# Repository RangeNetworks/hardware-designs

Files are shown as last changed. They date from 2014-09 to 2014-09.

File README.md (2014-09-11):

Range Networks SDR1 Open Source Software-Defined Radio
======================================================

The Range Networks SDR1 consists of two individual PCBs that work in tandem, referred to as the SDR module and the RF module (or board). The SDR module provides signal processing and digital data transfer between the RF signals and the host. The RF module provides the wireless transmission of the data. The SDR and RF module boards are each on a 5.5" x 3.25" PCB outline. This is a stacked design with a single interface connector between them. The RF module uses the same PCB layout with different component stuffing options and is capable of supporting the following frequency bands: 850, 900, 1800, 1900 MHz. The SDR1 is based in large part on the USRP1 design.

The design resources provided are as follows:

- Software-defined radio (SDR) module
  - Schematics in pdf format
  - BOM in text format
  - Gerber files with assembly and fabrication drawings
  - NVM file for Silicon Labs Si5332C OTP eeprom
- RF module
  - Schematics in pdf format
  - BOM in text format: Low band and High band
  - Gerber files with assembly and fabrication drawings

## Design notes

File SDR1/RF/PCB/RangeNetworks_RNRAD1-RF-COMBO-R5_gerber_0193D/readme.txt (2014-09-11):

ALL OF THE RAD1 PCB DESIGN IS PROVIDED UNDER THE TERMS OF THIS CREATIVE COMMONS PUBLIC LICENSE ("CCPL" OR "LICENSE"). 
THE WORK IS PROTECTED BY COPYRIGHT AND/OR OTHER APPLICABLE LAW. ANY USE OF THE WORK OTHER THAN AS 
AUTHORIZED UNDER THIS LICENSE OR COPYRIGHT LAW IS PROHIBITED. 

See http://creativecommons.org/licenses/by-sa/3.0/legalcode

Board Name: RF-Combo 			Customer: Range Networks
Fab Part Number: RNRAD1-RF-COMBO-R5	Revision: 5

ARTWORK FILENAME CONTROL CHART:

GERBER FILENAME	   		PCB DESIGN LAYER

layer01.art		=    	top - component side
layer02.art		=	layer 02 - gnd plane
layer03.art		=	layer 03 - pwr plane
layer04.art		=	bottom - solder side

paste_top.art      	=	component side pastemask
paste_bot.art     	=	solder side pastemask
silk_top.art      	=	component side silkscreen
silk_bot.art     	=	solder side silkscreen
solder_top.art		=	component side soldermask
solder_bot.art		=	solder side soldermask

fab.art			=	fabrication drawing
assy.art		=	assembly drawing

Reference Drawings:

fab.PDF			=	fabrication drawing
assy.PDF		=	assembly drawing 

Additional Support Files:
	
RNRAD1-RF-COMBO-R5-1-4.drl	NC Drill information Layer 1 to 4
RNRAD1-RF-COMBO-R5.cad		FABmaster extract file
RNRAD1-RF-COMBO-R5.ipc		Export of IPC 356D netlist
RNRAD1-RF-COMBO-R5.rou		Route file
rnrad1-rf-combo-r5.tgz		Valor ODB++
art_param.txt			Gerber output setup information
ncdrill.log			NC Drill report
nc_param.txt			NC Parameter report
place_txt.txt			Export of assembly component placement
readme.txt	 		Gerber ZIP file content information

Special notes:

1. Two shorts in Valor - U3 and U6 pin 2 connects to their tabs (a mech pin).
2. There are two known dangling traces, leave them please.

=================================================
Rocket EMS, Inc
2380 Bering Drive
San Jose, Ca 95131

Design contact: Craig Schieferstein (408)955-0528 x1203 cell (408)888-7351
Email contact: cschieferstein@rocketems.com
Sales contact: Scott Schaetzle (408)315-5192

If there are any question regarding the data please call Craig Schieferstein.

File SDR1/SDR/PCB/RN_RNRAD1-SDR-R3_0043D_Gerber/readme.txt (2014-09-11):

ALL OF THE RAD1 PCB DESIGN IS PROVIDED UNDER THE TERMS OF THIS CREATIVE COMMONS PUBLIC LICENSE ("CCPL" OR "LICENSE"). 
THE WORK IS PROTECTED BY COPYRIGHT AND/OR OTHER APPLICABLE LAW. ANY USE OF THE WORK OTHER THAN AS 
AUTHORIZED UNDER THIS LICENSE OR COPYRIGHT LAW IS PROHIBITED. 

See http://creativecommons.org/licenses/by-sa/3.0/legalcode

Board Name: SDR 				Customer: Range Networks
Fab Part Number: RNRAD1-SDR-R3		Revision: 3

ARTWORK FILENAME CONTROL CHART:

GERBER FILENAME		PCB DESIGN LAYER

layer01.art		=    	top - component side
layer02.art		=	layer 02 – gnd plane
layer03.art		=	layer 03 – sig1 signal
layer04.art		=	layer 04 – sig2 signal
layer05.art		=	layer 05 – pwr plane
layer06.art		=	bottom - solder side

paste_top.art		=	component side pastemask
paste_bot.art		=	solder side pastemask
silk_top.art		=	component side silkscreen
silk_bot.art		=	solder side silkscreen
solder_top.art		=	component side soldermask
solder_bot.art		=	solder side soldermask
fab.art			=	fabrication drawing
assy.art			=	assembly drawing

Reference Drawings:

fab.PDF			=	fabrication drawing
assy.PDF		=	assembly drawing 

Additional Support Files:
	
RNRAD1-SDR-R3-1-6.drl		NC Drill information Layer 1 to 6
RNRAD1-SDR-R3.cad		FABmaster extract file
RNRAD1-SDR-R3.ipc		Export of IPC 356D netlist
RNRAD1-SDR-R3.rou		Route file
RNRAD1-SDR-R3.tgz		Valor ODB++
art_param.txt			Gerber output setup information
ncdrill.log				NC Drill report
nc_param.txt			NC Parameter report
place_txt.txt			Export of assembly component placement
readme.txt	 		Gerber ZIP file content information

==================================================================
If you would like to order PCBs directly you may contact the following

Rocket EMS, Inc
2380 Bering Drive
San Jose, Ca 95131

Sales contact: Scott Schaetzle (408)636-1616 cell (408)315-5192
Design contact: Donn Grigsby (408)636-1607 cell (510)590-3007
Email contact: dgrigsby@rocketems.com

If there are any question regarding the data please call Donn Grigsby.

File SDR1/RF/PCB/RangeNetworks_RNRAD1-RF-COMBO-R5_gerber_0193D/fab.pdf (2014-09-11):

0.062
10%
.5 oz

1.0 oz

1.0 oz

.5 oz

1.4

12.3
0.6

28.0
1.2

12.3
1.2

1.4
0.6

NESS

THICK

PLATING

PLATING

2X2113 1X2116

2X2113 1X2116
CORE

LAYER04 BOTTOM

LAYER03 PWR

LAYER02 GND

LAYER01 TOP

LAYER

23.0 mils

19.0 mils

23.0 mils

LINE WIDTH

50

50

50

IMPEDANCE

+/- 10%

+/- 10%

+/- 10%

# SEE NOTES

16. Add thieving to balance the copper distribution. The thieving consists of
15. Data Verification
14. Markings
13. Inspection
12. Impedance controlled construction and certification is required.
11. Bow and twist
10. Packaging
9. Cleanliness
8. Electrical test
7. Silkscreen
6. Finish
5. Remove all unused inner layers pads.
4. Drilling
3. Soldermask
2. Material
1. Specifications (unless otherwise specified):

15.0 Vendor will do a netlist to Gerber compare with the supplied

14.0 Fab will be permanently marked or etched with

Rocket EMS

13.0 Automatic optical inspection of all layers required.

(.007" per linear inch).

11.0 Maximum board warpage in any direction shall not exceed 0.7%

10.0 There shall be a max of 25 units per package, individually wrapped

9.1 Finished boards must conform to no more than 10 uG/in(squared) ionic

9.0 Boards shall be free of fiber glass dust or any other foreign material.

The test system shall provide a means of limiting the energy delivery to

Isolation Resistance: 10M Ohms, measured with a voltage of 200 Volts.

test not to exceed 10 Volts.

10 milliAmperes or less. Maximum open circuit voltage during continuity

8.2 Continuity: Test threshold not to exceed 10 Ohms, using a test current of

8.1 Apply test stamp in an area clear of silk and parts on solder side of PCB.

8.0 All boards must be 100% electrically tested for open and shorts at10 Volts.

7.4 Registration to be +/-.005 and must pass peel test.

7.3 Minimum clearance between silkscreen legend and vias, pads or holes,

7.2 Burn out silkscreen with soldermask.

7.1 No silkscreen allowed on exposed lands or in holes.

7.0 Silkscreen using | non-conductive epoxy or equivalent (both sides).

6.2 Finished boards shall not have nicks, scratches,

6.1 Plate holes thru with copper .0010 min to .002 max. thickness. Finished

6.0 Surface finish: Immersion gold, 2-5 micro-inches over 100

4.4 Minimum annular ring is 0.001". No breakout is permitted.

4.3 An N.C Drill file has been supplied-see drill table.

4.2 All hole diameters to be +/-.003 unless otherwise specified.

4.1 All holes to be +/-.003 from true position unless otherwise specified.

4.0 All hole diameters are finished sizes.

3.2 Via pads are encroached. Bottom side test pad vias are exposed.

3.1 Soldermask over -

3.0 Soldermask both sides with ( | color) liquid

2.3 Number of Layers:

2.2 Color to be opaque.

2.1 See stack up for copper weights

2.0 Natural Epoxy/Glass Laminate

1.3 Board must be compliant with UL 94V-0 .

1.2 Use | PCB artwork

1.1 Producibility study - it is the responsibility of the supplier

1.0 Unless otherwise defined on this drawing, fabricate board per

features will be maintained.

50 mil round pads on 100 mil centers. A 100 mil keepout of all etched

contamination.

to be .005

their e-mail address is located in the readme.txt.

An e-mail confirmation is required and should be sent to the designer found written permission must be obtained prior to proceeding.

IPC-356D file prior to releasing to manufacturing. If discrepancies are

Manufacturer's logo, date of Fab manufacture and UL 94V-0 rating.

and packaged so as to prevent damage during handling,shipping and storage.

voids, exposed copper, poor plating or mis-drilled holes.

hole size dimensions apply after plating.

micro-inches minimum of electroless nickel photo-imageable soldermask, .003 max. thickness.

measured over area free of soldermask.

w/Tg min of 170 degrees Celsius, thick +/-10 % standards, and of any specifications that cannot be met.

corrections made or recomendations to ensure conformance to

(in advance of manufacturing) of any changes, revisions, or

applicable specifications. | must be advised in writing

anufacturability in the supplier's process compliant to all

to conduct a thorough review of the artwork and media for

Current Revision of IPC-6012, Class 2 requirements.

Range Networks

03/22/12

white

bare copper.

4

Range Networks

green

FR-4.
.062

RNRAD1-RF-COMBO-R5

# RF-COMBO BOARD

# RANGE NETWORKS

# FAB DRAWING

Range Networks

5

# 1 RNRAD1-RF-COMBO-R5

FIGURE | SIZE | TOLERANCE | PLATED | QTY
| 0.010 | +.003/-.010 | PLATED | 330
| 0.012 | +.003/-.012 | PLATED | 633
| 0.018 | +/-.002 | PLATED | 46
| 0.040 | +/-.003 | PLATED | 7
| 0.060 | +/-.003 | PLATED | 10
| 0.070 | +/-.003 | PLATED | 21
| 0.125 | +/-.003 | PLATED | 4
| 0.040 | +/-.003 | NON-PLATED | 2

ALL UNITS ARE IN INCHES

HOLE CHART

| DRAWING REV 07
.005 1 .01 | | | RNRAD1-RF-COMBO-R5 | 5
SCALE: NONE | | SHEET 1OF 1

DESCRIPTION

.110

.789

2.211

3.000

3.110

0

.1100
.621

5.42

## REF

5.200

5.310

3.22

## REF

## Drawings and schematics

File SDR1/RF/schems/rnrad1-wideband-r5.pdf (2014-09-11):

## DGND ON DYN?

### IOB_P

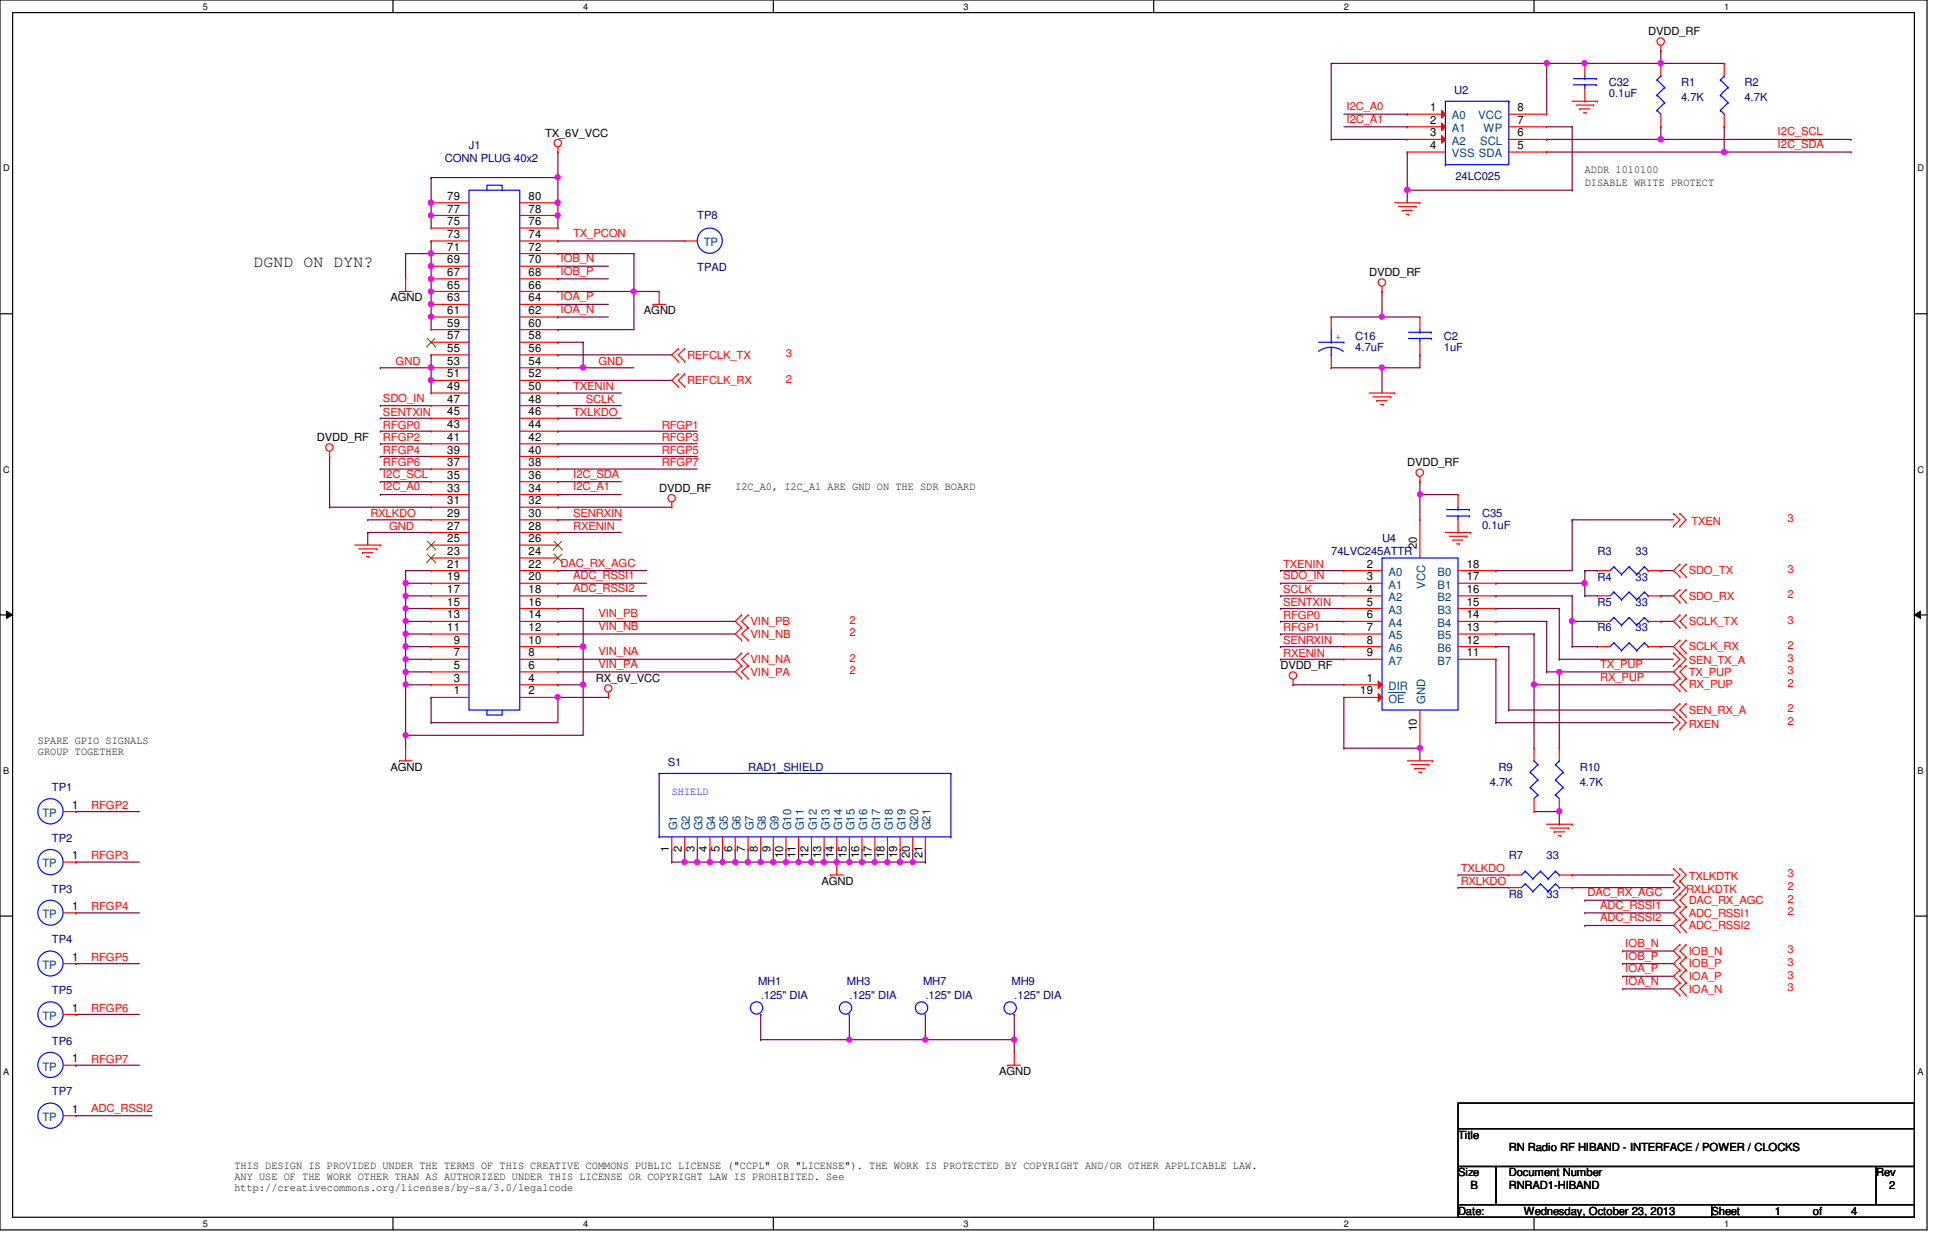
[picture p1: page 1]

I2C_A0, I2C_A1 ARE GND ON THE SDR BOARD

RN Radio RF HIBAND - INTERFACE / POWER / CLOCKS

THIS DESIGN IS PROVIDED UNDER THE TERMS OF THIS CREATIVE COMMONS PUBLIC LICENSE ("CCPL" OR "LICENSE"). THE WORK IS PROTECTED BY COPYRIGHT AND/OR OTHER APPLICABLE LAW.
ANY USE OF THE WORK OTHER THAN AS AUTHORIZED UNDER THIS LICENSE OR COPYRIGHT LAW IS PROHIBITED. See
http://creativecommons.org/licenses/by-sa/3.0/legalcode

## LOW-PASS FILTER: MIXER OUT TO BASEBAND AMPS

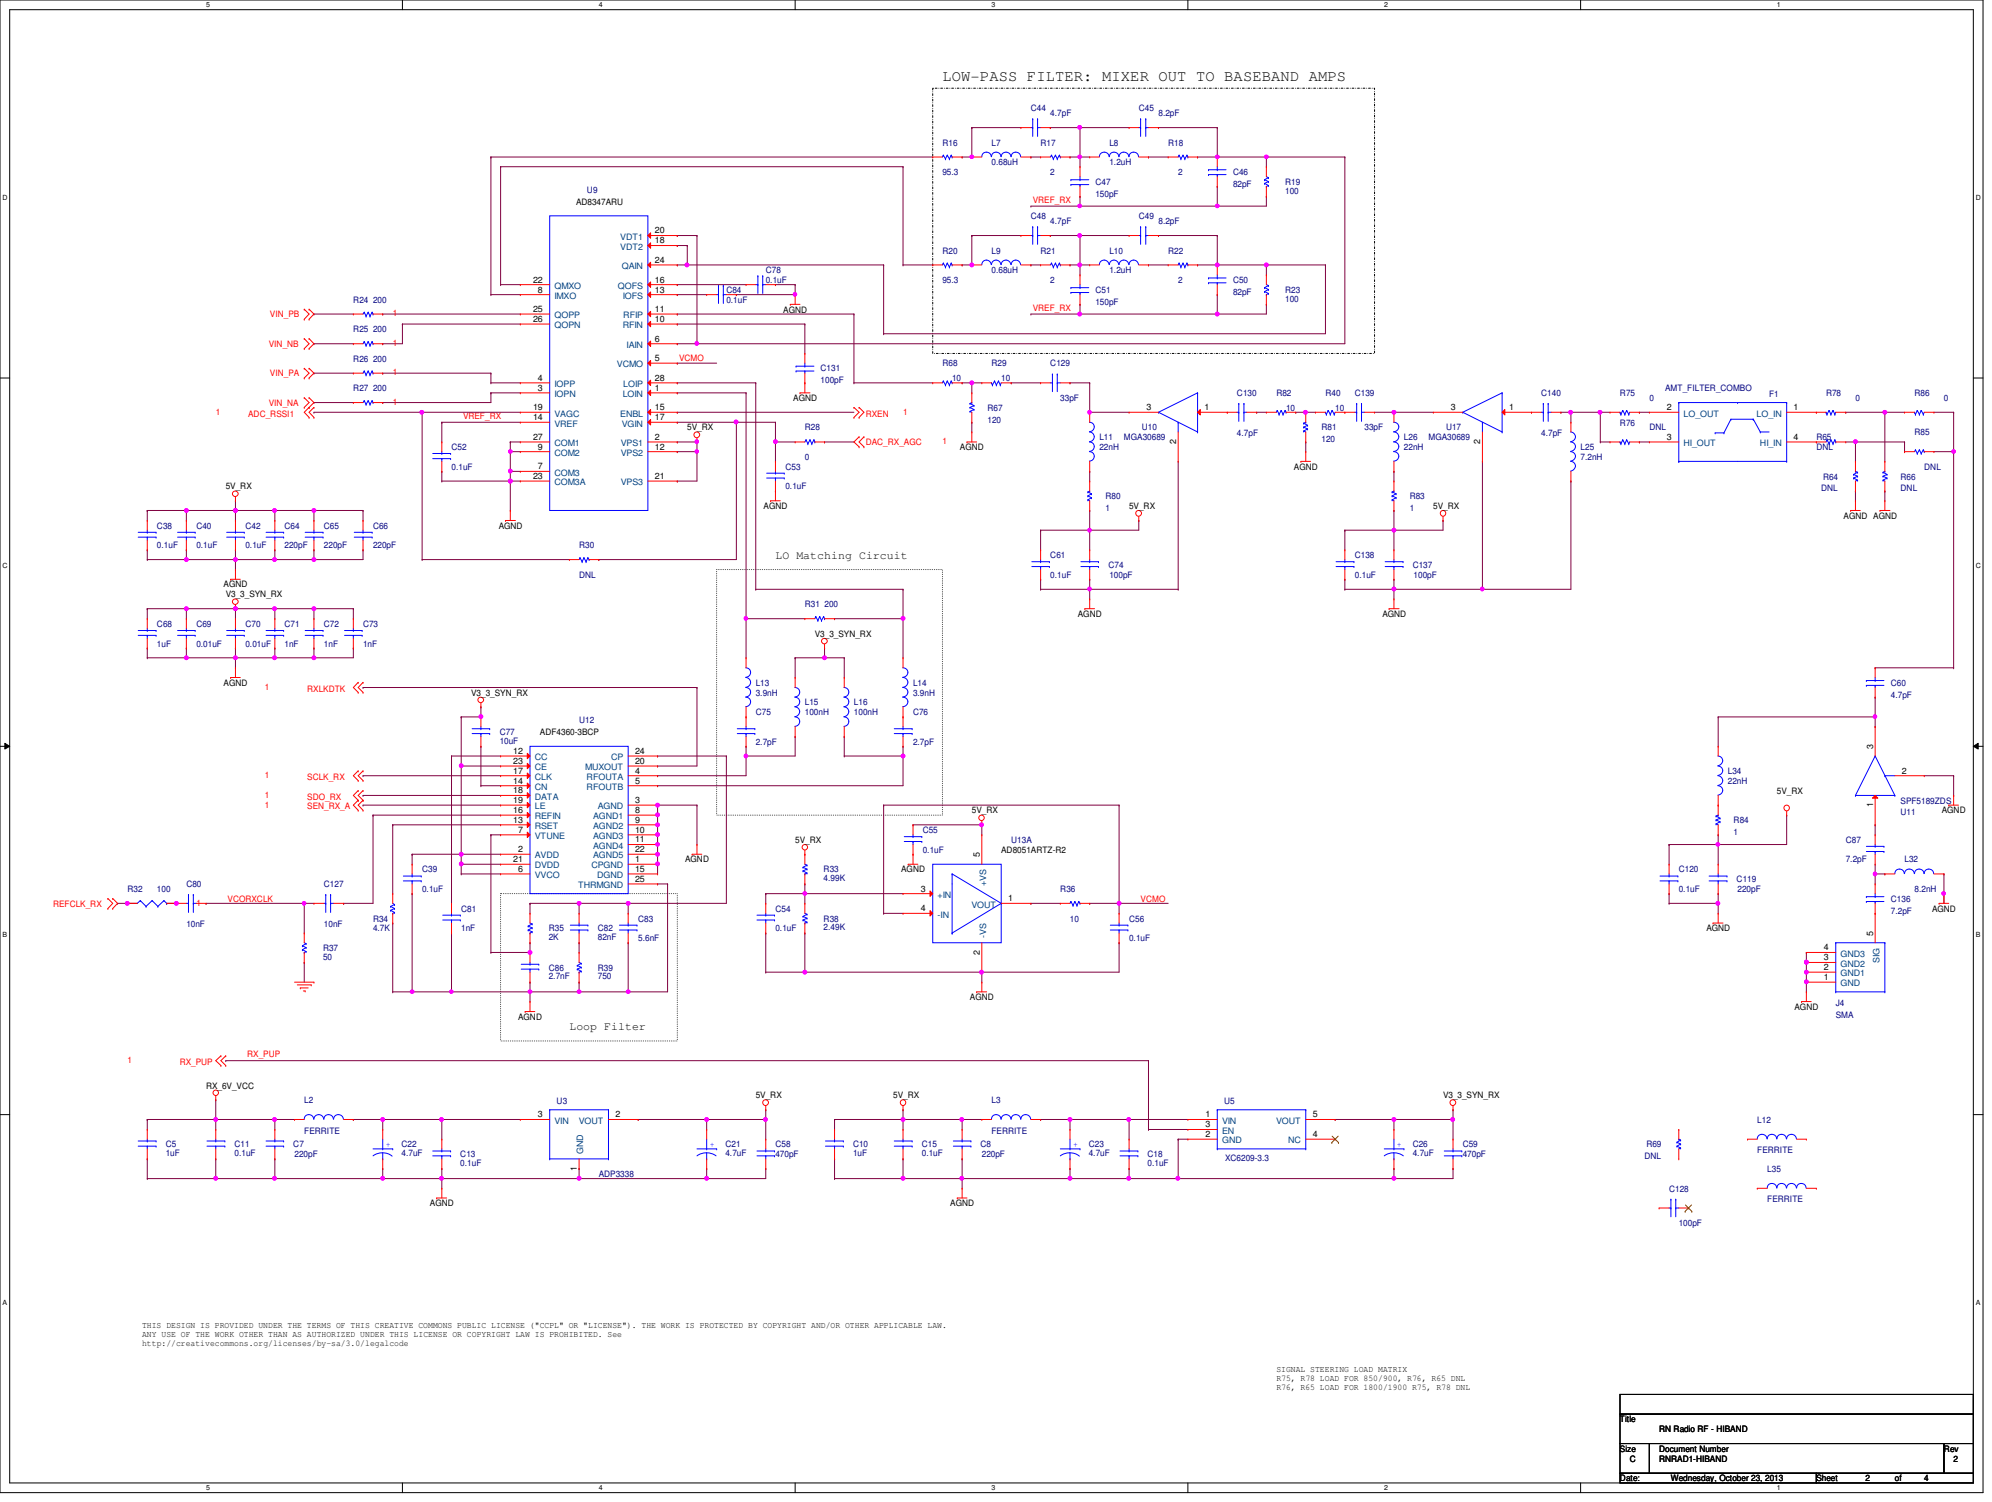
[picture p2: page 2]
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

SIGNAL STEERING LOAD MATRIX
R75, R78 LOAD FOR 850/900, R76, R65 DNL
R76, R65 LOAD FOR 1800/1900 R75, R78 DNL

RN Radio RF - HIBAND

## LOW-PASS FILTER

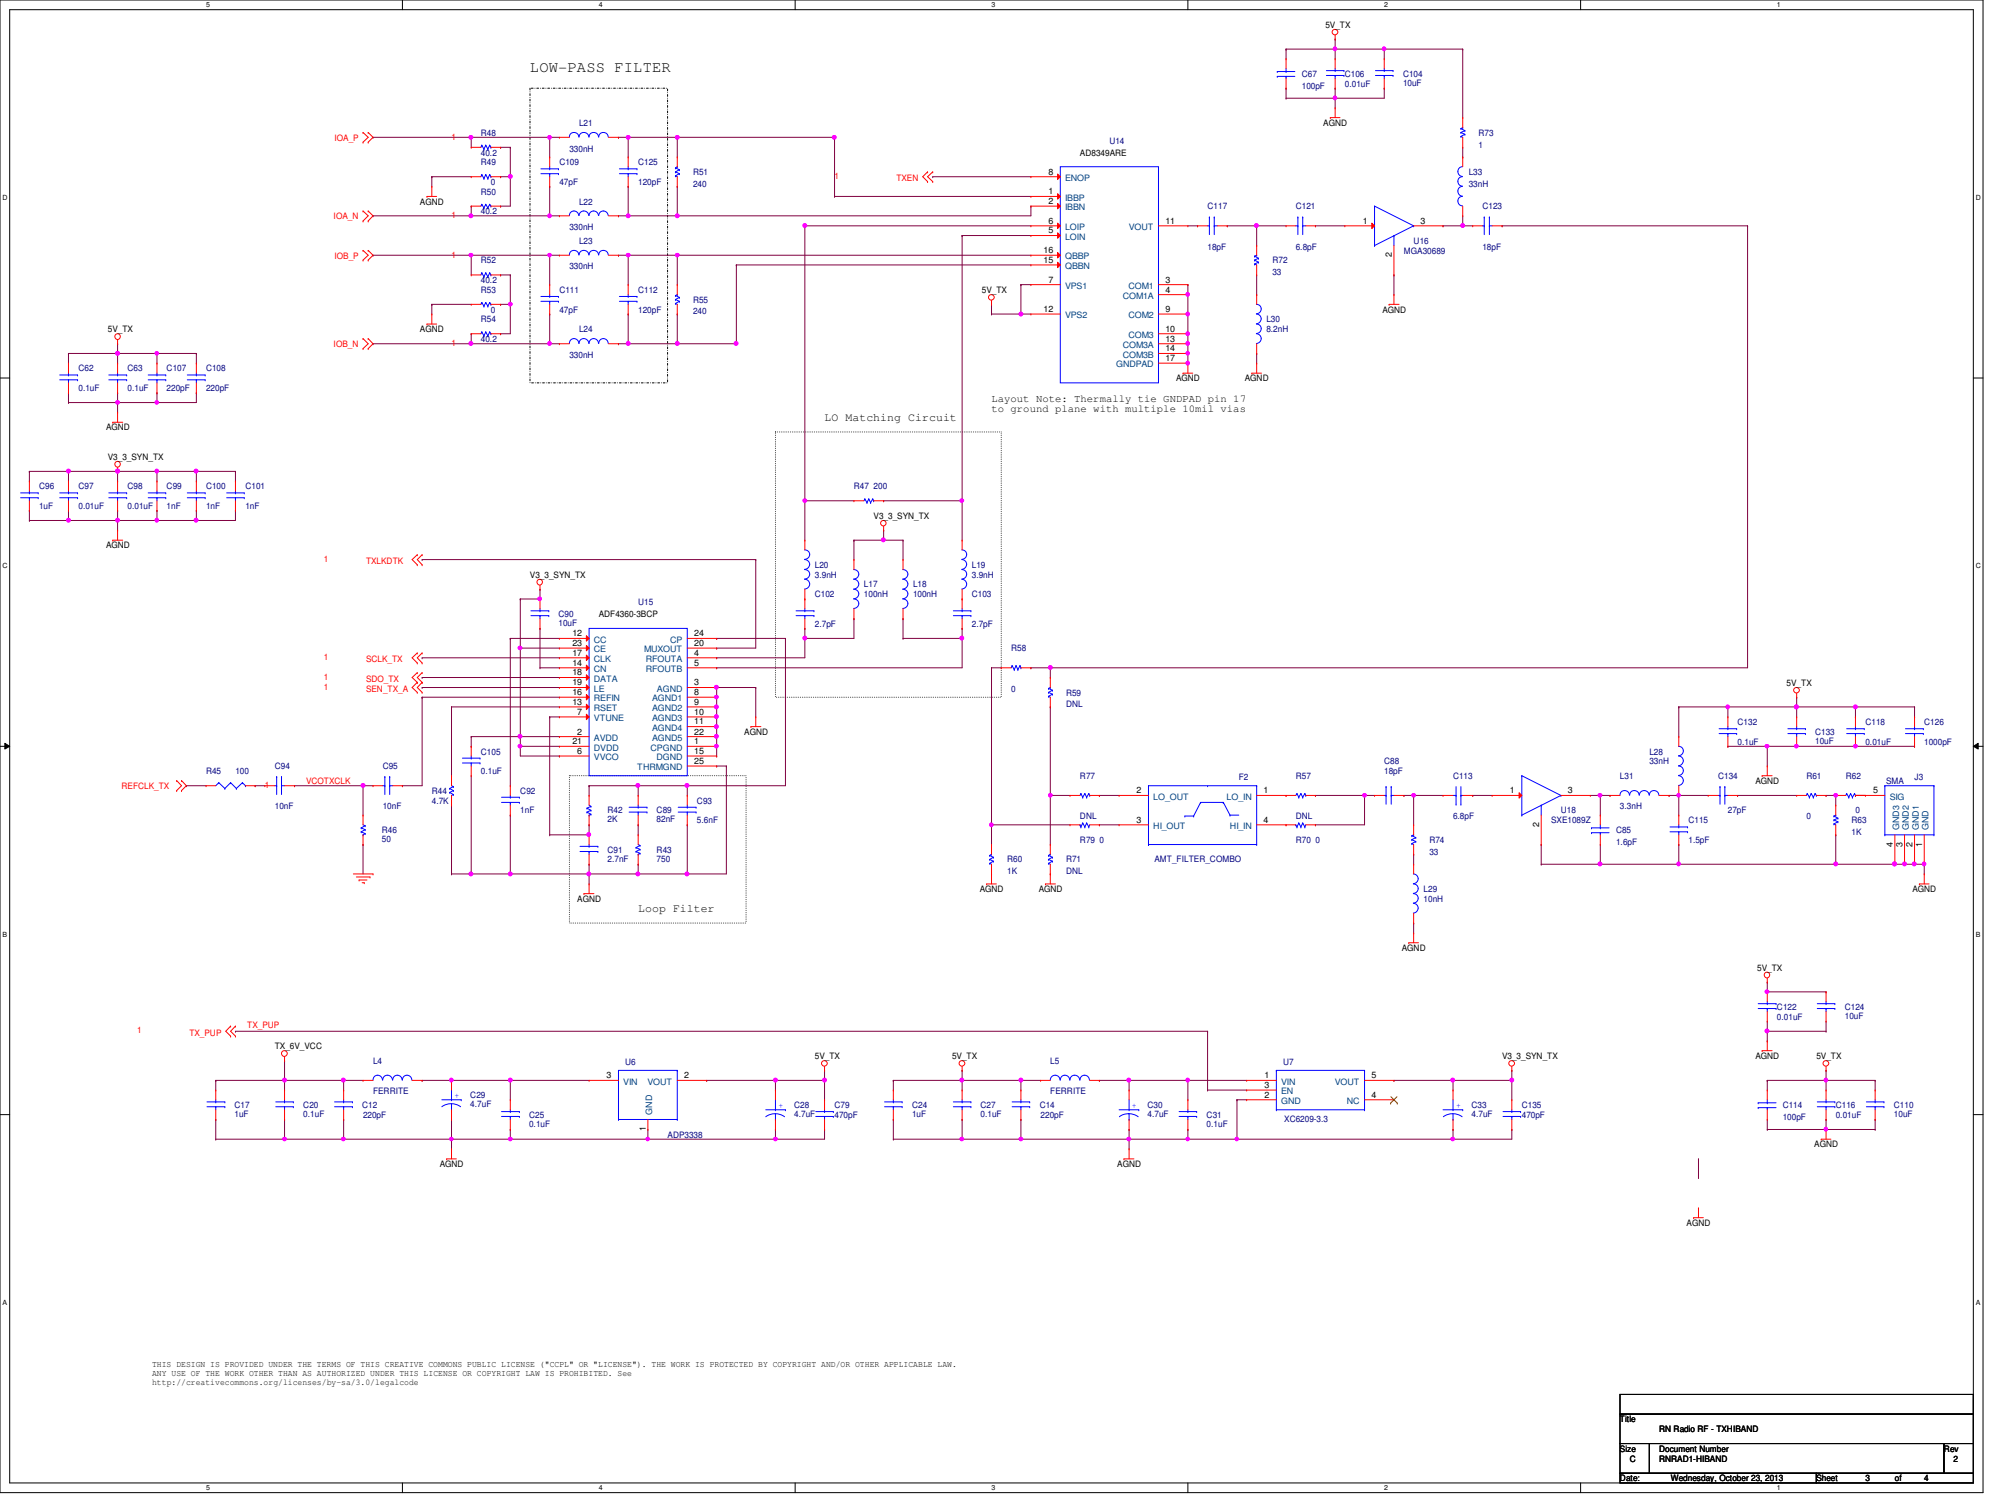
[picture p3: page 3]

Layout Note: Thermally tie GNDPAD pin 17
to ground plane with multiple 10mil vias

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

RN Radio RF - TXHIBAND

# CONFIGURATION NOTES FOR MULTIBAND ASSEMBLY

# * 1800MHz CONFIGURATION

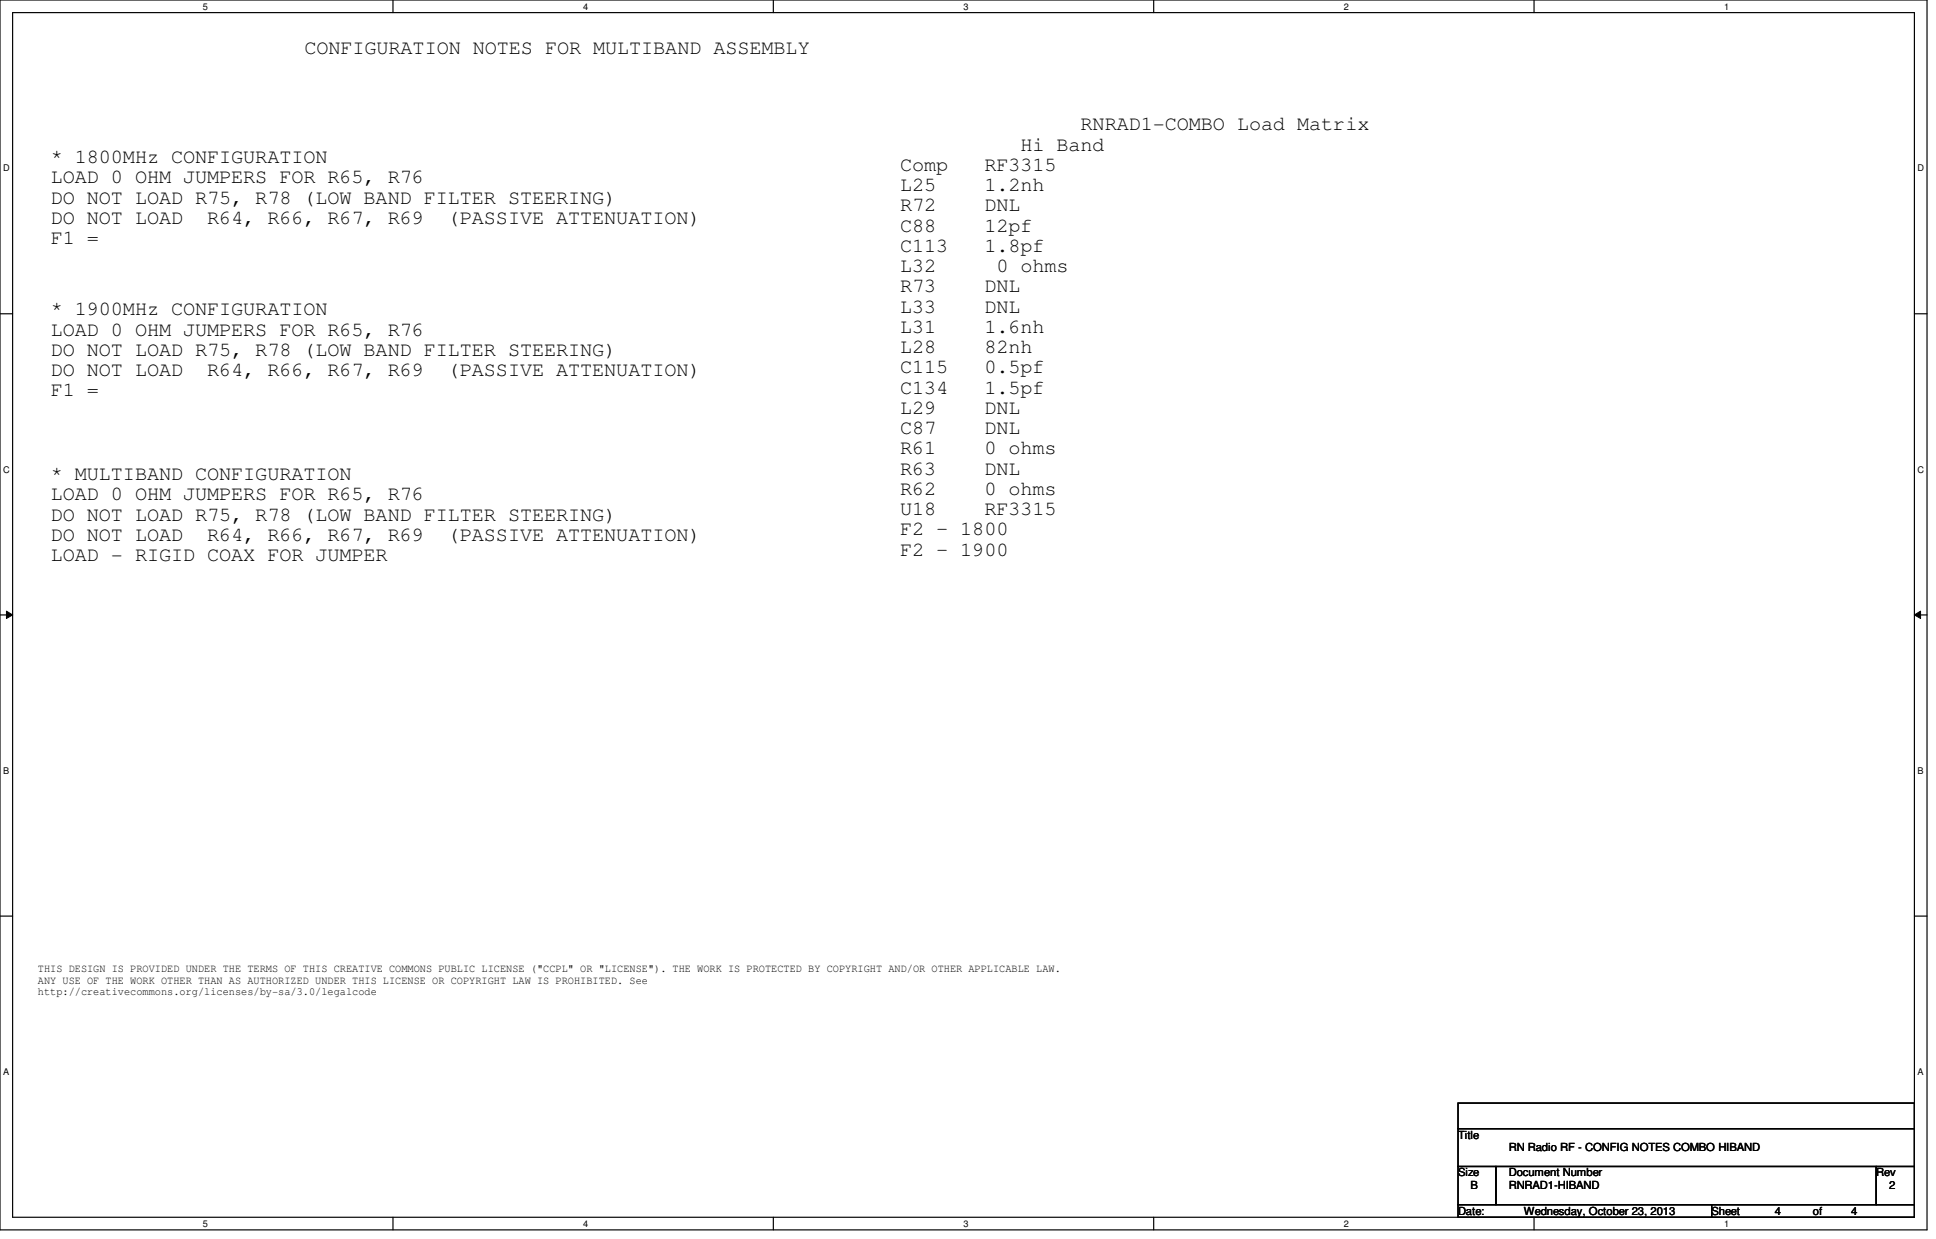
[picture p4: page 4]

LOAD 0 OHM JUMPERS FOR R65, R76
DO NOT LOAD R75, R78 (LOW BAND FILTER STEERING)

* 1900MHz CONFIGURATION

* MULTIBAND CONFIGURATION
LOAD - RIGID COAX FOR JUMPER

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

RN Radio RF - CONFIG NOTES COMBO HIBAND

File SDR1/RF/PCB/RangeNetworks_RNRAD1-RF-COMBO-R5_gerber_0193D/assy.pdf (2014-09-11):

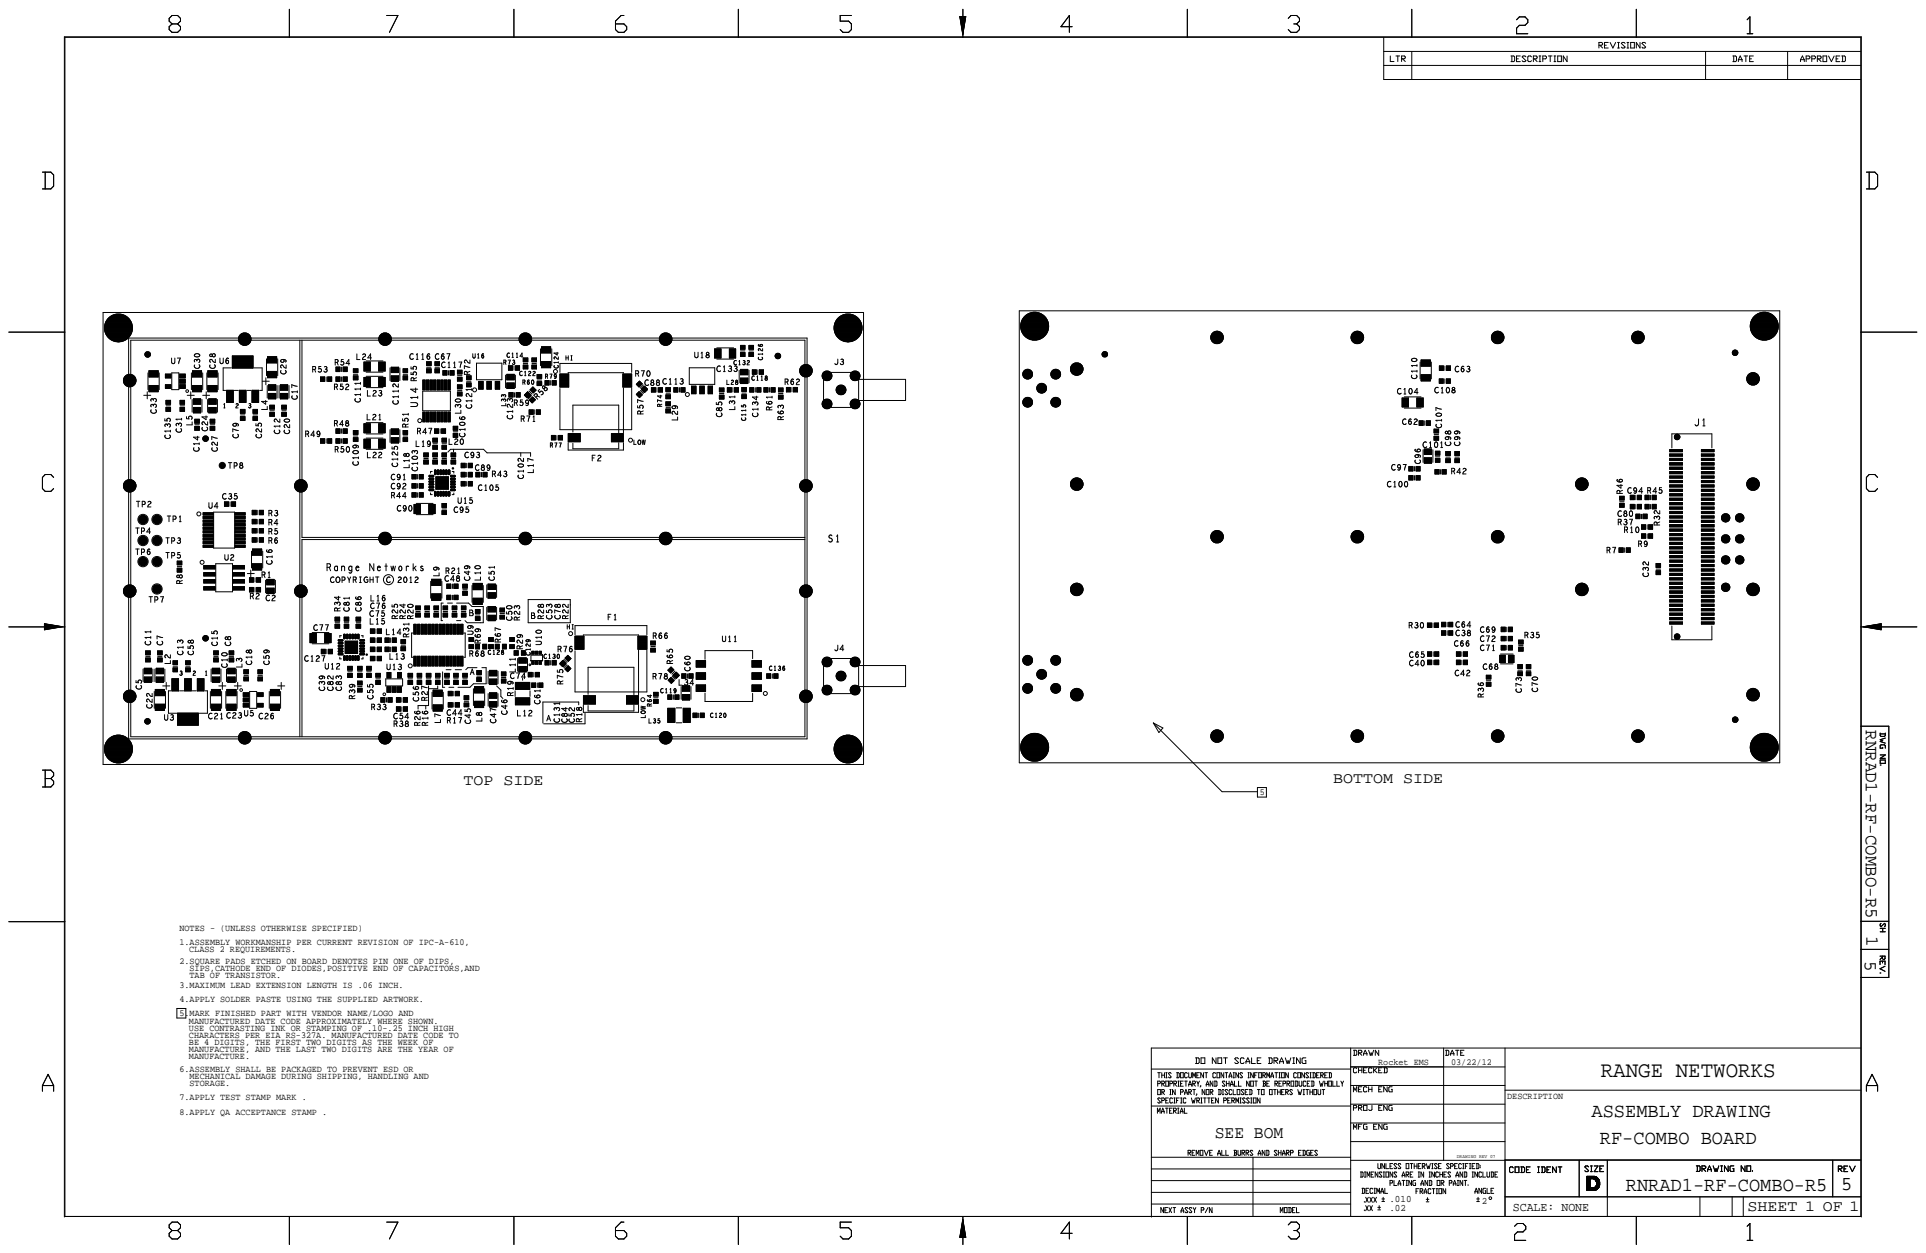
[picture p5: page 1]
SHEET 1 OF 1; 5 1 RNRAD1-RF-COMBO-R5; RANGE NETWORKS; RNRAD1-RF-COMBO-R5; SCALE: NONE; SEE BOM; BOTTOM SIDE; Rocket EMS; TOP SIDE; DRAWING REV 07; DESCRIPTION

NOTES - (UNLESS OTHERWISE SPECIFIED)
1.ASSEMBLY WORKMANSHIP PER CURRENT REVISION OF IPC-A-610,
CLASS 2 REQUIREMENTS.
2.SQUARE PADS ETCHED ON BOARD DENOTES PIN ONE OF DIPS,
SIPS,CATHODE END OF DIODES,POSITIVE END OF CAPACITORS,AND
TAB OF TRANSISTOR.
3.MAXIMUM LEAD EXTENSION LENGTH IS .06 INCH.
4.APPLY SOLDER PASTE USING THE SUPPLIED ARTWORK.
5.MARK FINISHED PART WITH VENDOR NAME/LOGO AND
MANUFACTURED DATE CODE APPROXIMATELY WHERE SHOWN.
USE CONTRASTING INK OR STAMPING OF .10-.25 INCH HIGH
CHARACTERS PER EIA RS-327A. MANUFACTURED DATE CODE TO
BE 4 DIGITS, THE FIRST TWO DIGITS AS THE WEEK OF
MANUFACTURE, AND THE LAST TWO DIGITS ARE THE YEAR OF
MANUFACTURE.
6.ASSEMBLY SHALL BE PACKAGED TO PREVENT ESD OR
MECHANICAL DAMAGE DURING SHIPPING, HANDLING AND
STORAGE.
7.APPLY TEST STAMP MARK .
8.APPLY QA ACCEPTANCE STAMP .

ASSEMBLY DRAWING
RF-COMBO BOARD

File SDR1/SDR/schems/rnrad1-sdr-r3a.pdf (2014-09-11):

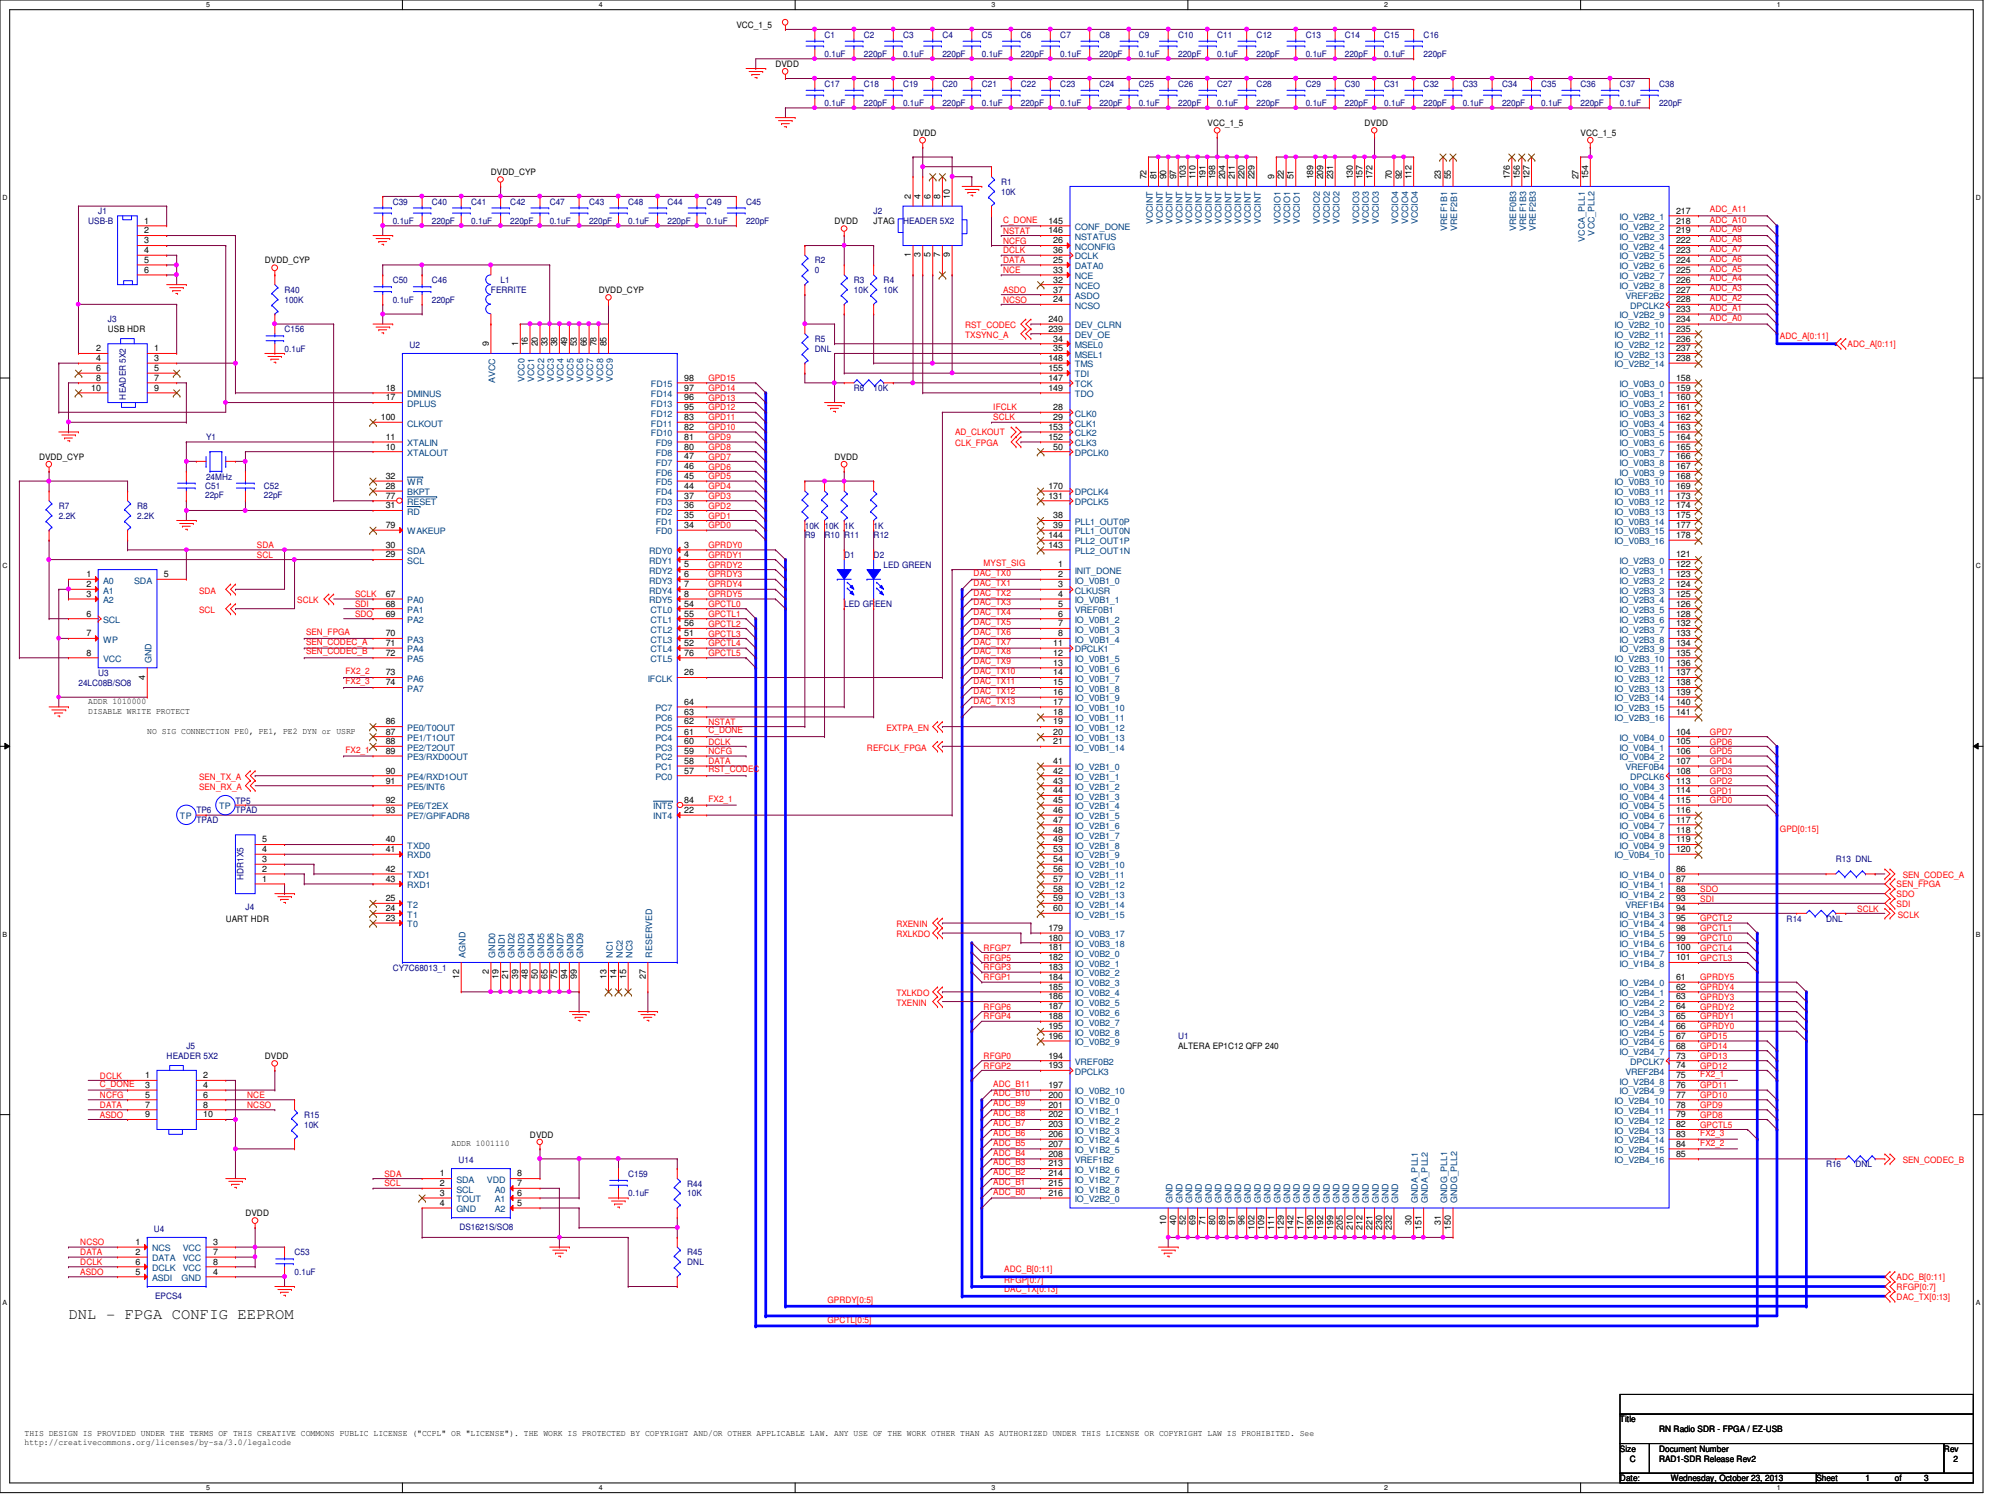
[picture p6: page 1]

DPLUS 17 | GPD13
CLKOUT 100 XTALIN 11 | GPD12

NO SIG CONNECTION PE0, PE1, PE2 DYN or USRP

DNL - FPGA CONFIG EEPROM

THIS DESIGN IS PROVIDED UNDER THE TERMS OF THIS CREATIVE COMMONS PUBLIC LICENSE ("CCPL" OR "LICENSE"). THE WORK IS PROTECTED BY COPYRIGHT AND/OR OTHER APPLICABLE LAW. ANY USE OF THE WORK OTHER THAN AS AUTHORIZED UNDER THIS LICENSE OR COPYRIGHT LAW IS PROHIBITED. See
http://creativecommons.org/licenses/by-sa/3.0/legalcode

RN Radio SDR - FPGA / EZ-USB

### ADC_A0 ADC_A1

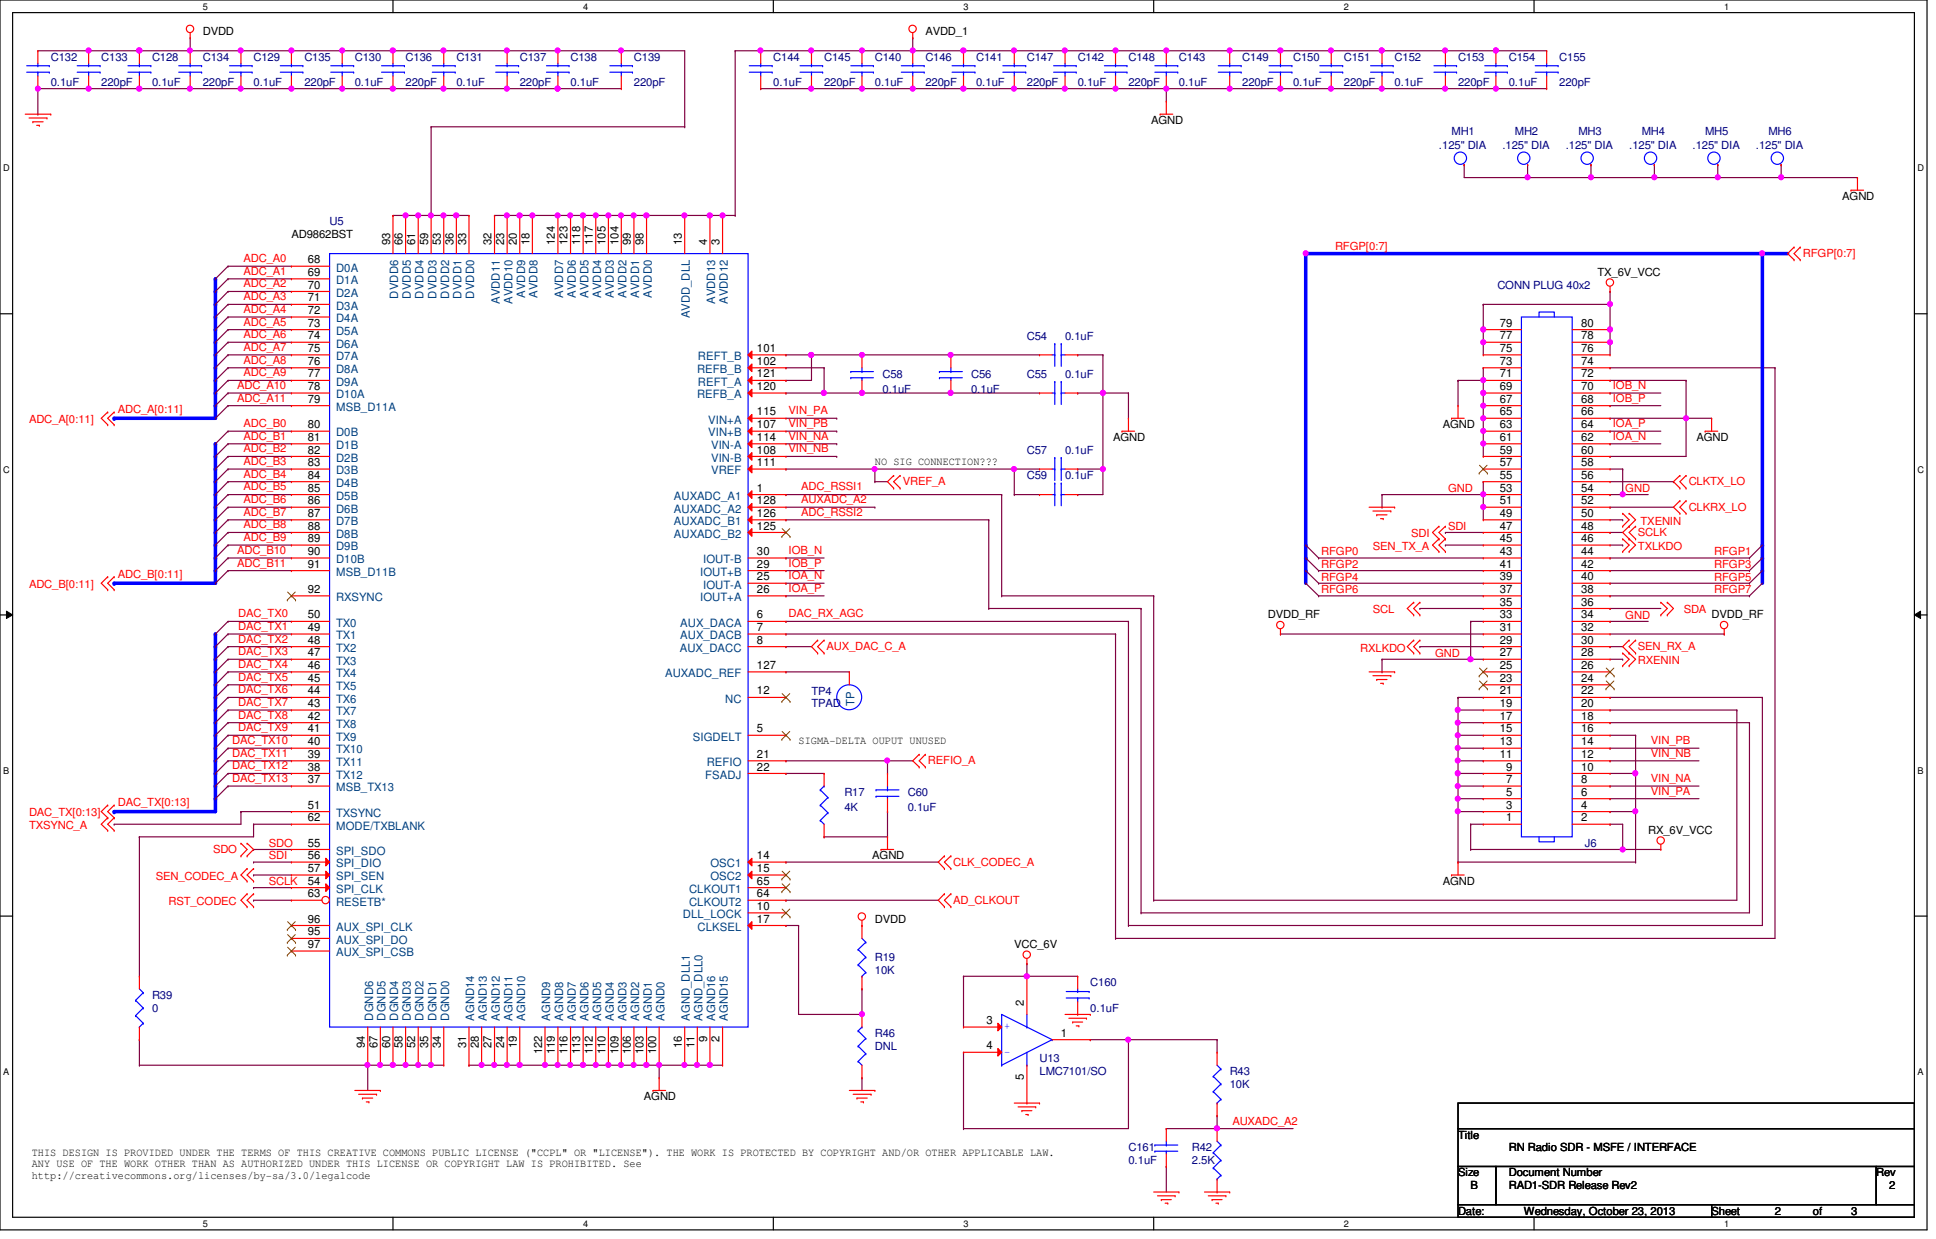
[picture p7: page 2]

SIGMA-DELTA OUPUT UNUSED

RN Radio SDR - MSFE / INTERFACE

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

# NEED ONE MORE .1UF AT OUTPUT VCC_6V

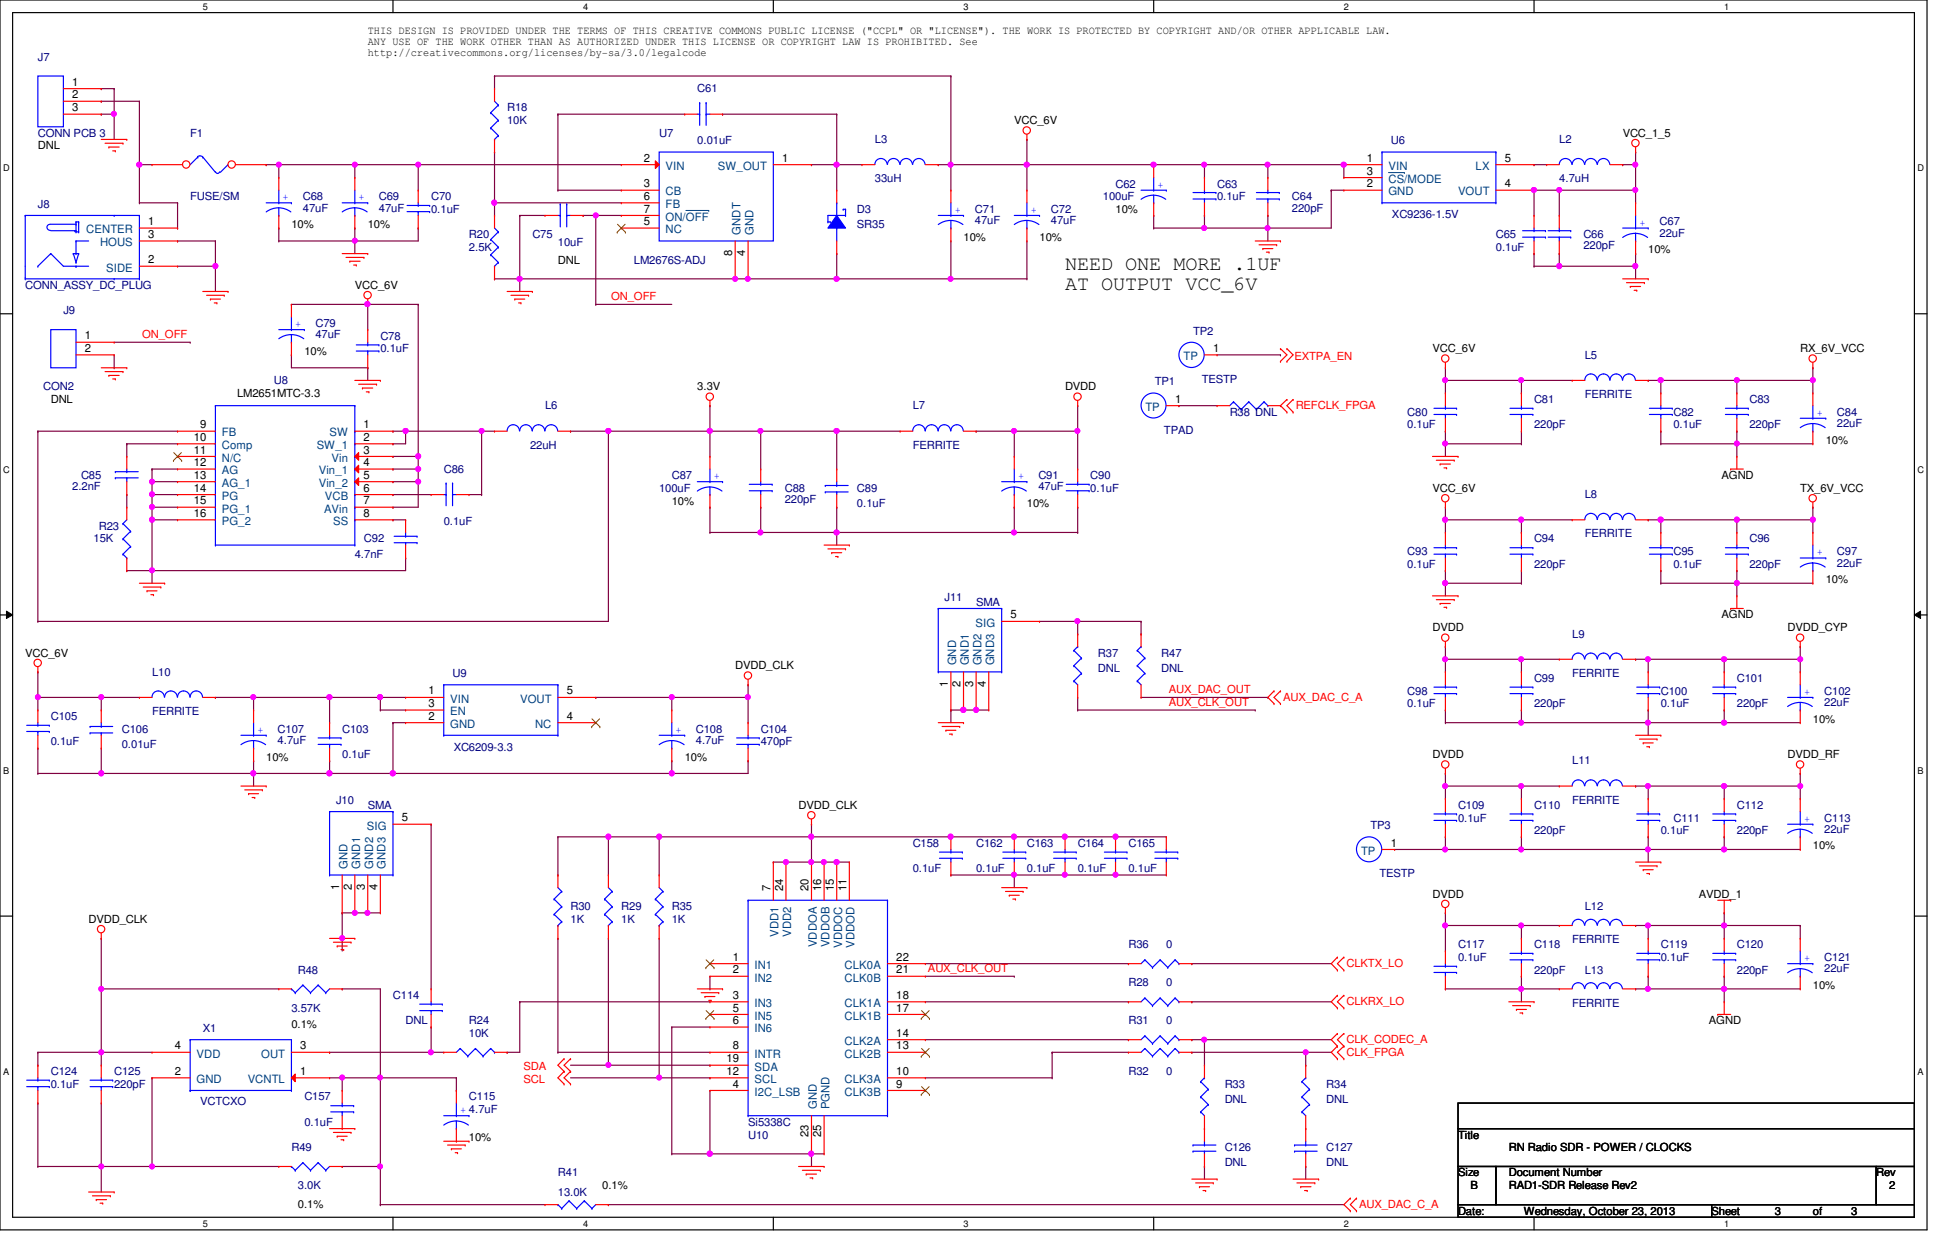
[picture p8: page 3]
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

AG 12 | 4
AG_1 13 | 5
PG 14 | 6
PG_1 15 | 7
PG_2 16 | 8

RN Radio SDR - POWER / CLOCKS

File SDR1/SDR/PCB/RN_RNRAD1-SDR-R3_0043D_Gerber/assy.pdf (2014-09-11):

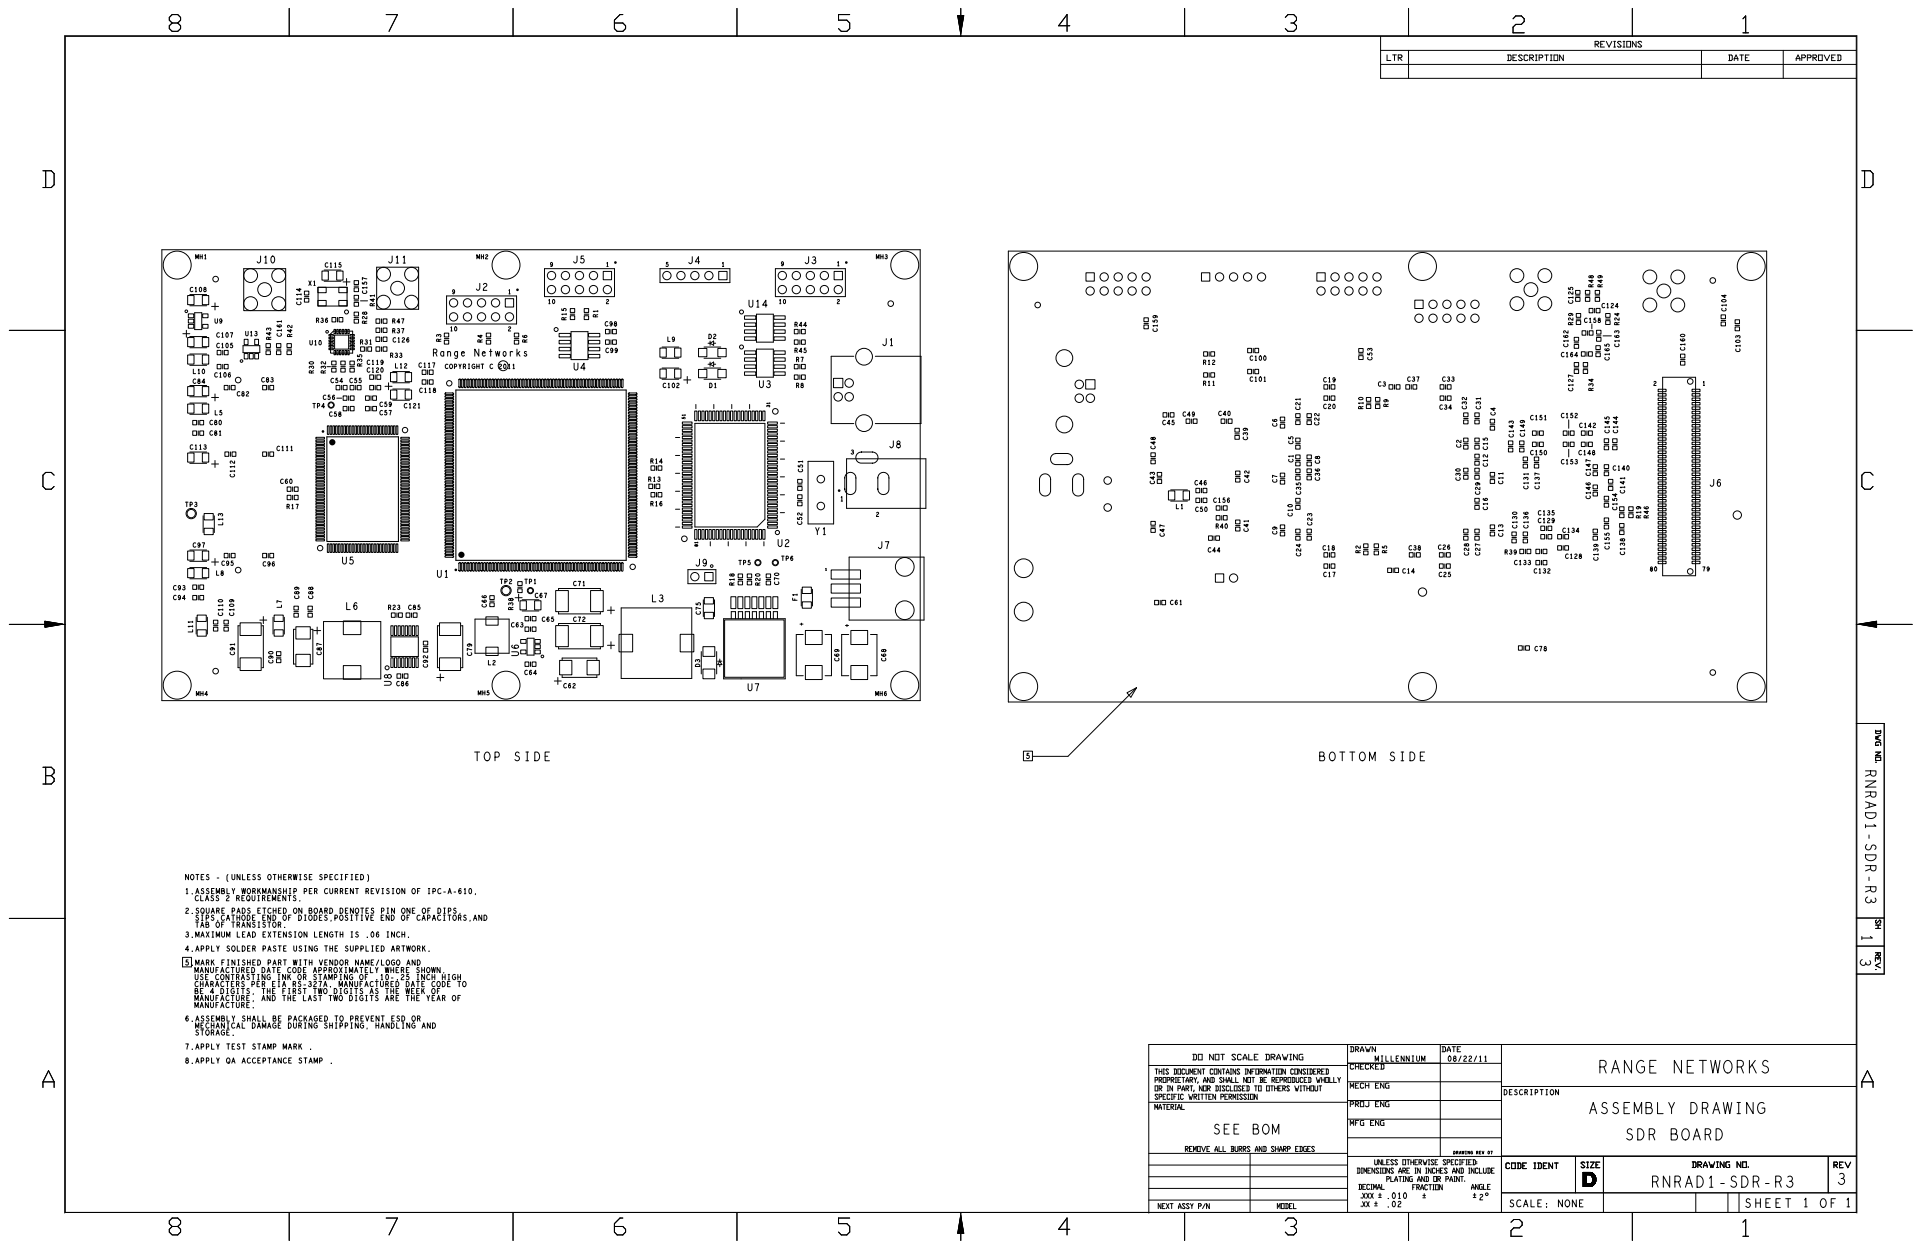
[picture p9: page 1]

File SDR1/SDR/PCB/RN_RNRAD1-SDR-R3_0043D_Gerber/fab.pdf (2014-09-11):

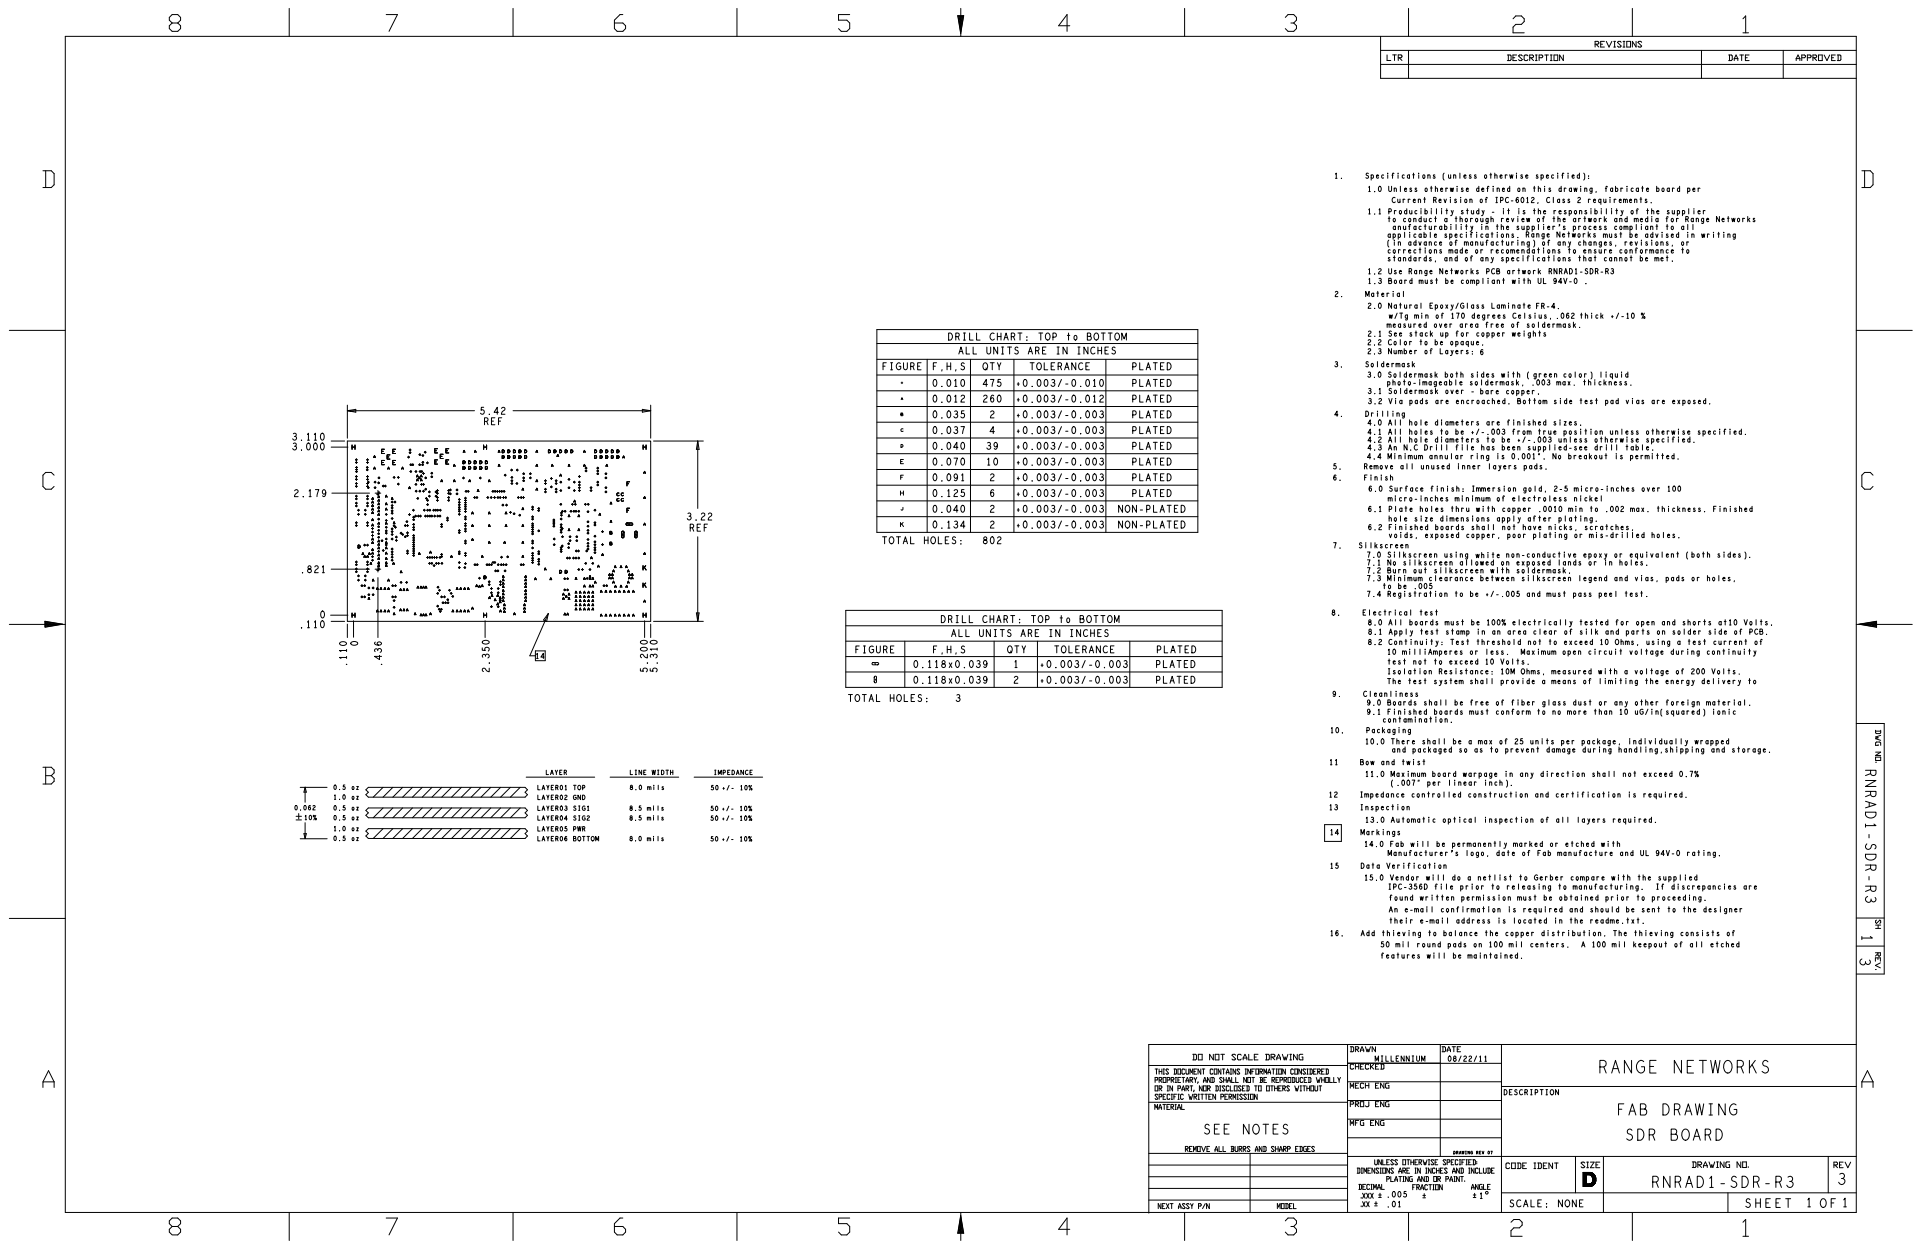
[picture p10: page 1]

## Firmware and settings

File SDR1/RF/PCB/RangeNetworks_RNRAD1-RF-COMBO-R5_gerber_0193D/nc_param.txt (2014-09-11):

INTEGER-PLACES         2
DECIMAL-PLACES         5
X-OFFSET               0.000000
Y-OFFSET               0.000000
FEEDRATE               1
COORDINATES            ABSOLUTE
OUTPUT-UNITS           ENGLISH
TOOL-ORDER             INCREASING
REPEAT-CODES           YES
SUPPRESS-LEAD-ZEROES   NO
SUPPRESS-TRAIL-ZEROES  NO
SUPPRESS-EQUAL         NO
TOOL-SELECT            NO
OPTIMIZE_DRILLING      NO
ENHANCED_EXCELLON      NO
HEADER                 none
LEADER                 12
CODE                   ASCII
SEPARATE               NO
DRILLING               LAYER-PAIR
BACKDRILL              NO
